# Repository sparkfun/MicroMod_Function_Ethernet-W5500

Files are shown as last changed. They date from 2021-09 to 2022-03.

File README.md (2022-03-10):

SparkFun MicroMod Ethernet Function Board - W5500
========================================

SparkFun MicroMod Ethernet Function Board - W5500 (https://www.sparkfun.com/products/18708)

[*SparkFun MicroMod Ethernet Function Board - W5500 (COM-18708)*](https://www.sparkfun.com/products/18708)

The SparkFun MicroMod Ethernet Function Board - W5500 provides Ethernet network connection as well as Power-over-Ethernet capabilities to a MicroMod project.

The W5500 Ethernet Controller from WIZnet is a TCP/IP embedded Ethernet controller that uses SPI communication protocol to allow up to eight independent sockets operate simultaneously. The W5500 SPI interface operates at up to 80MHz and supports fast SPI for high speed Ethernet communication. The chip also includes a Wake on Lan (WOL) operation and power down mode to help conserve power.

The board uses a Ag9900m Power-over-Ethernet (PoE) DC/DC converter module to power MicroMod assemblies from a PoE source such as a router or network switch. The DC/DC converter supplies 9 Watts @5V to connected devices. This Function Board configures the PoE supply voltage to the IEEE802.3af Alternate B power scheme. This power scheme uses the spare pairs in the Ethernet cable (4,5 and 7,8) for positive and negative DC voltage, isolating power delivery from the data lines.

Repository Contents
-------------------

* **/Documents** - Datasheet, Appnotes.
* **/Firmware** - HTTP Test.
* **/Hardware** - Eagle design files (.brd, .sch)

Documentation
-------------

* **[Hookup Guide](https://learn.sparkfun.com/tutorials/micromod-ethernet-function-board---w5500-hookup-guide)** - A basic Hookup Guide to get started with the MicroMod Ethernet Function Board - W5500.

Product Versions
----------------
* [COM-18708](https://www.sparkfun.com/products/18708) - Initial release

Version History
---------------
* v1.0 - Initial Release 

License Information
-------------------

This product is _**open source**_! 

Please review the LICENSE.md file for license information. 

If you have any questions or concerns on licensing, please contact technical support on our [SparkFun forums](https://forum.sparkfun.com/viewforum.php?f=152).

Distributed as-is; no warranty is given.

- Your friends at SparkFun.

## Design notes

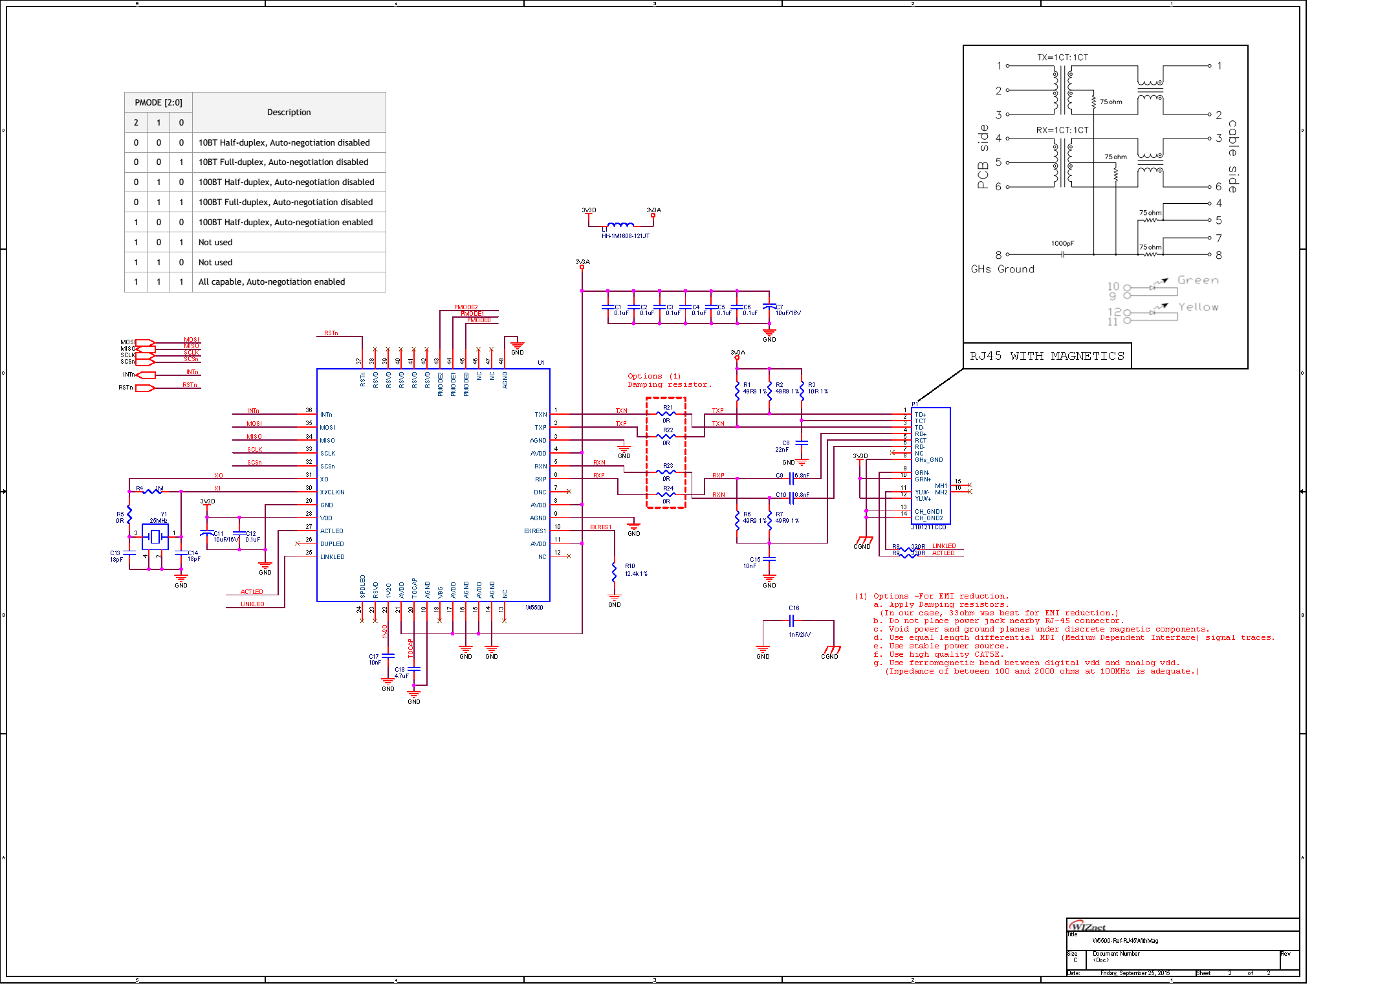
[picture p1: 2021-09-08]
Documents/w5500_sch.png

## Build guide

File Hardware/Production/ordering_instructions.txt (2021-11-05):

panel size, 129x137mm
PCB thickness, 0.8mm
number of layers, 2
bevel, Gold Fingers + 45° Finger Chamfered
soldermask color, Red
silkscreen color, White
oz copper, 1oz
finish, ENIG
stencils, none
pcs per panel, 6
min trace width, 0.1778mm / 0.0070in
min drill size, 0.3048mm / 0.0120in

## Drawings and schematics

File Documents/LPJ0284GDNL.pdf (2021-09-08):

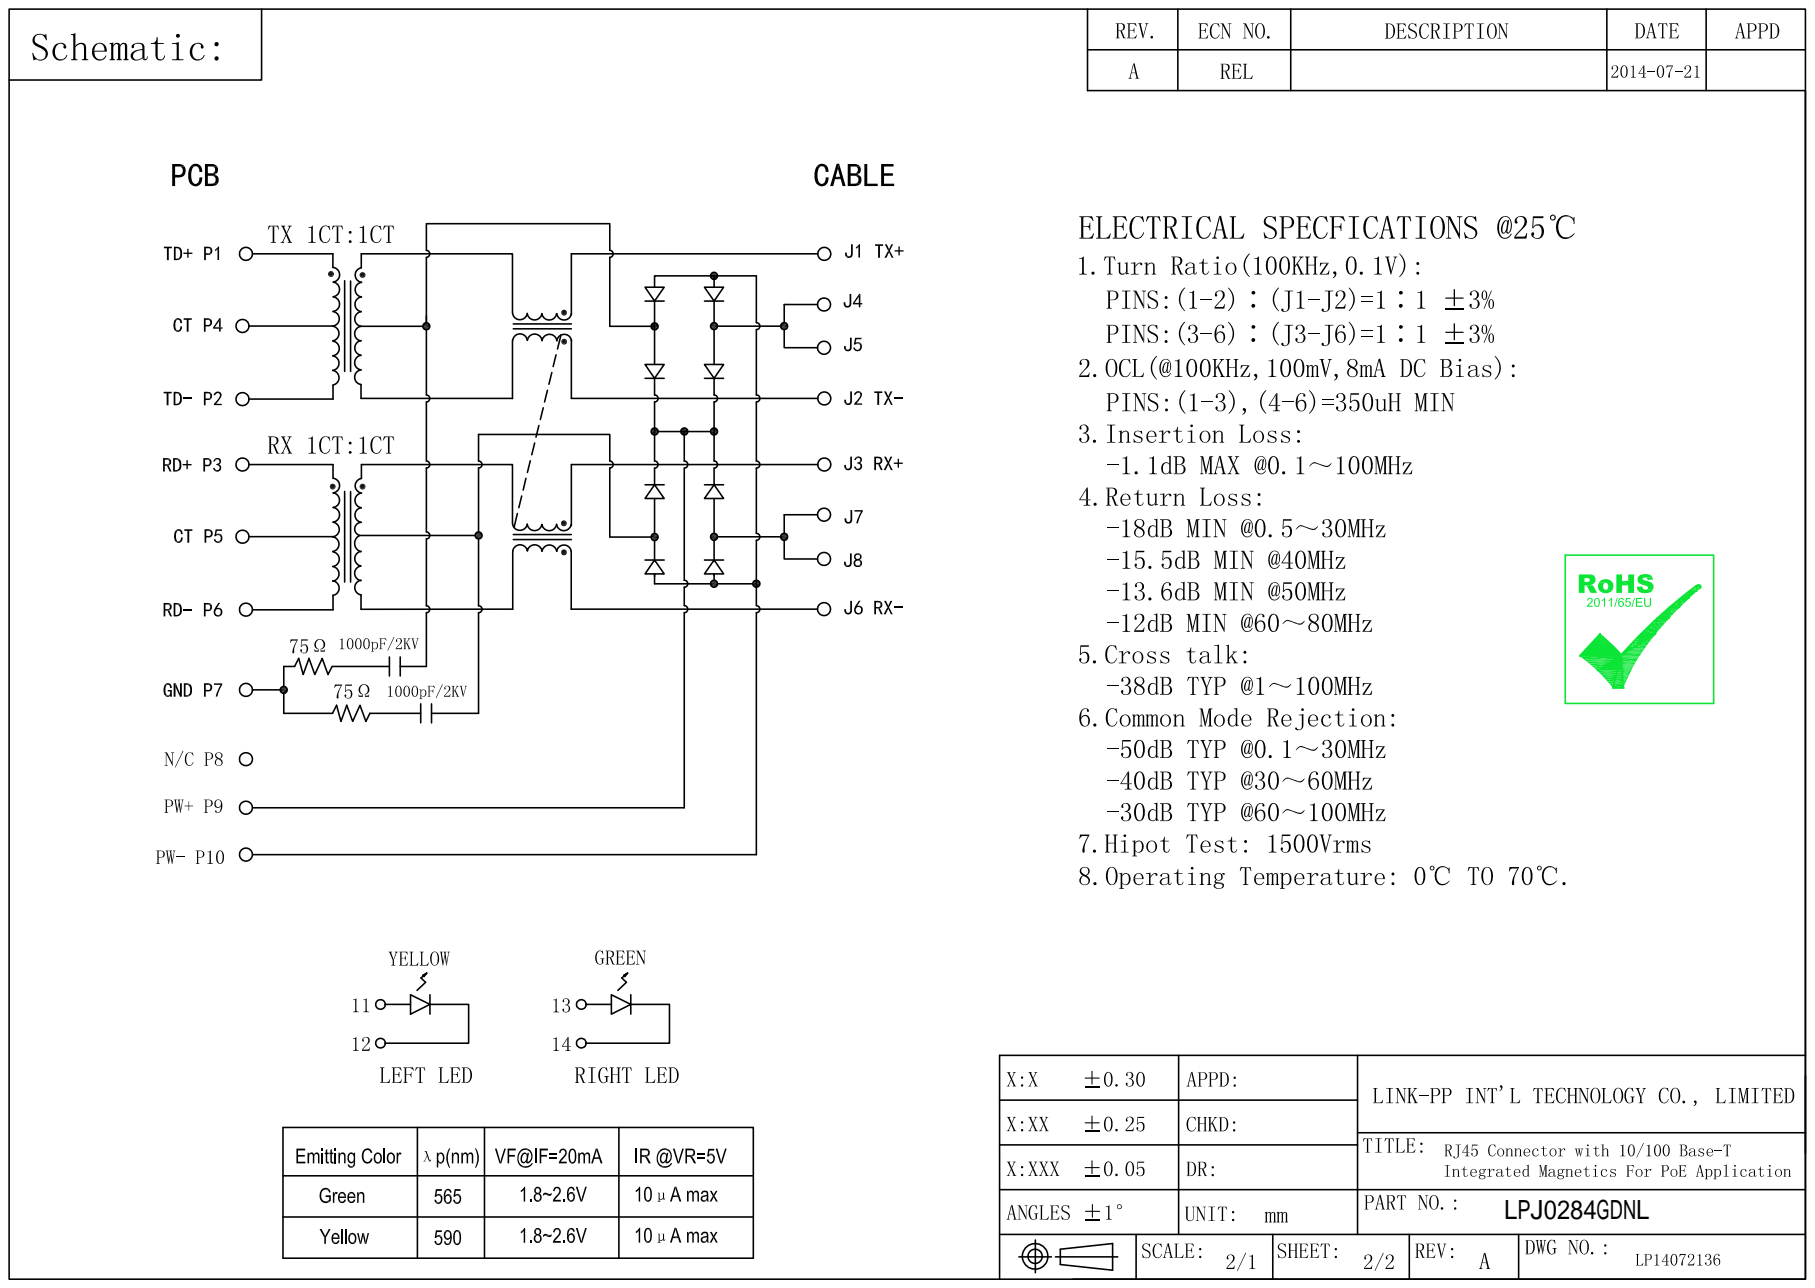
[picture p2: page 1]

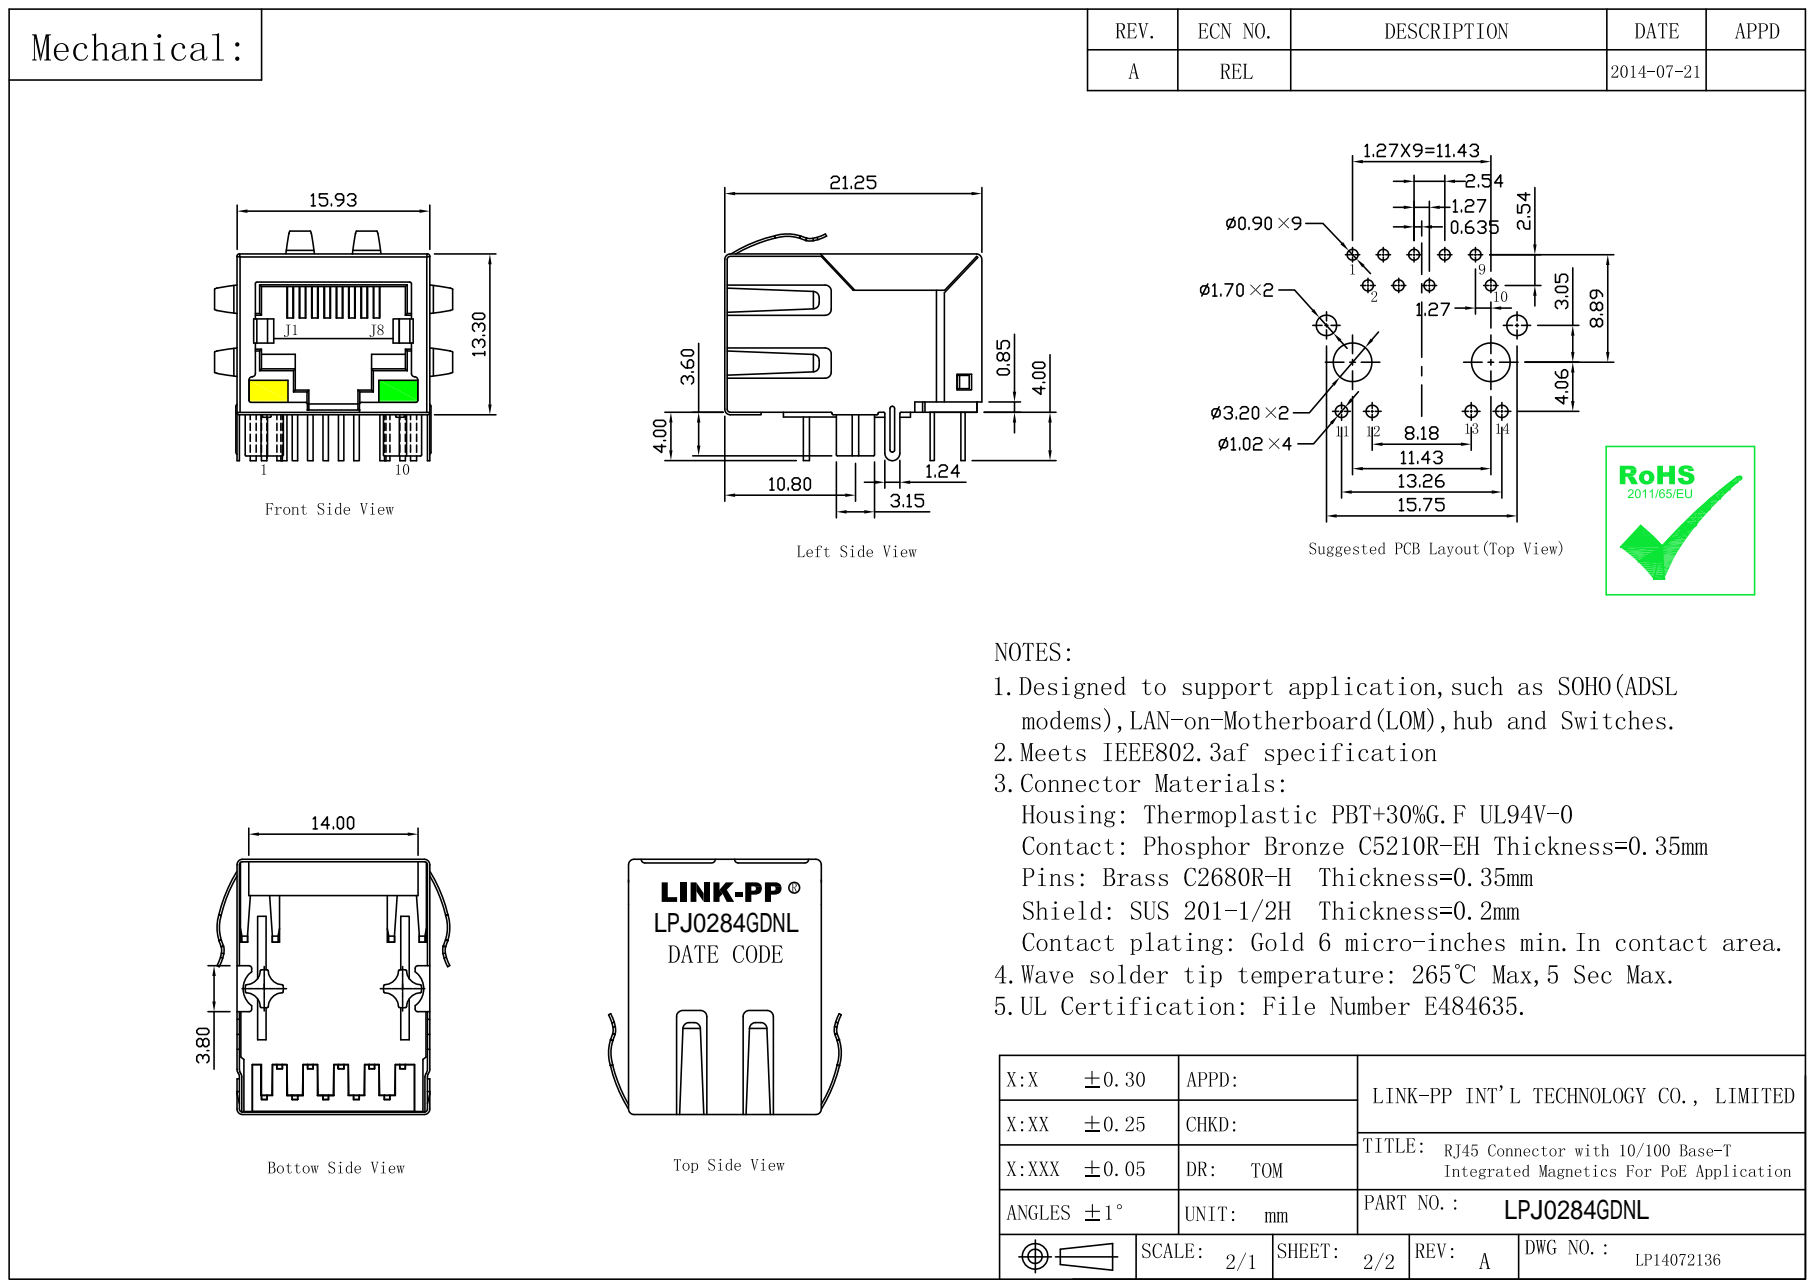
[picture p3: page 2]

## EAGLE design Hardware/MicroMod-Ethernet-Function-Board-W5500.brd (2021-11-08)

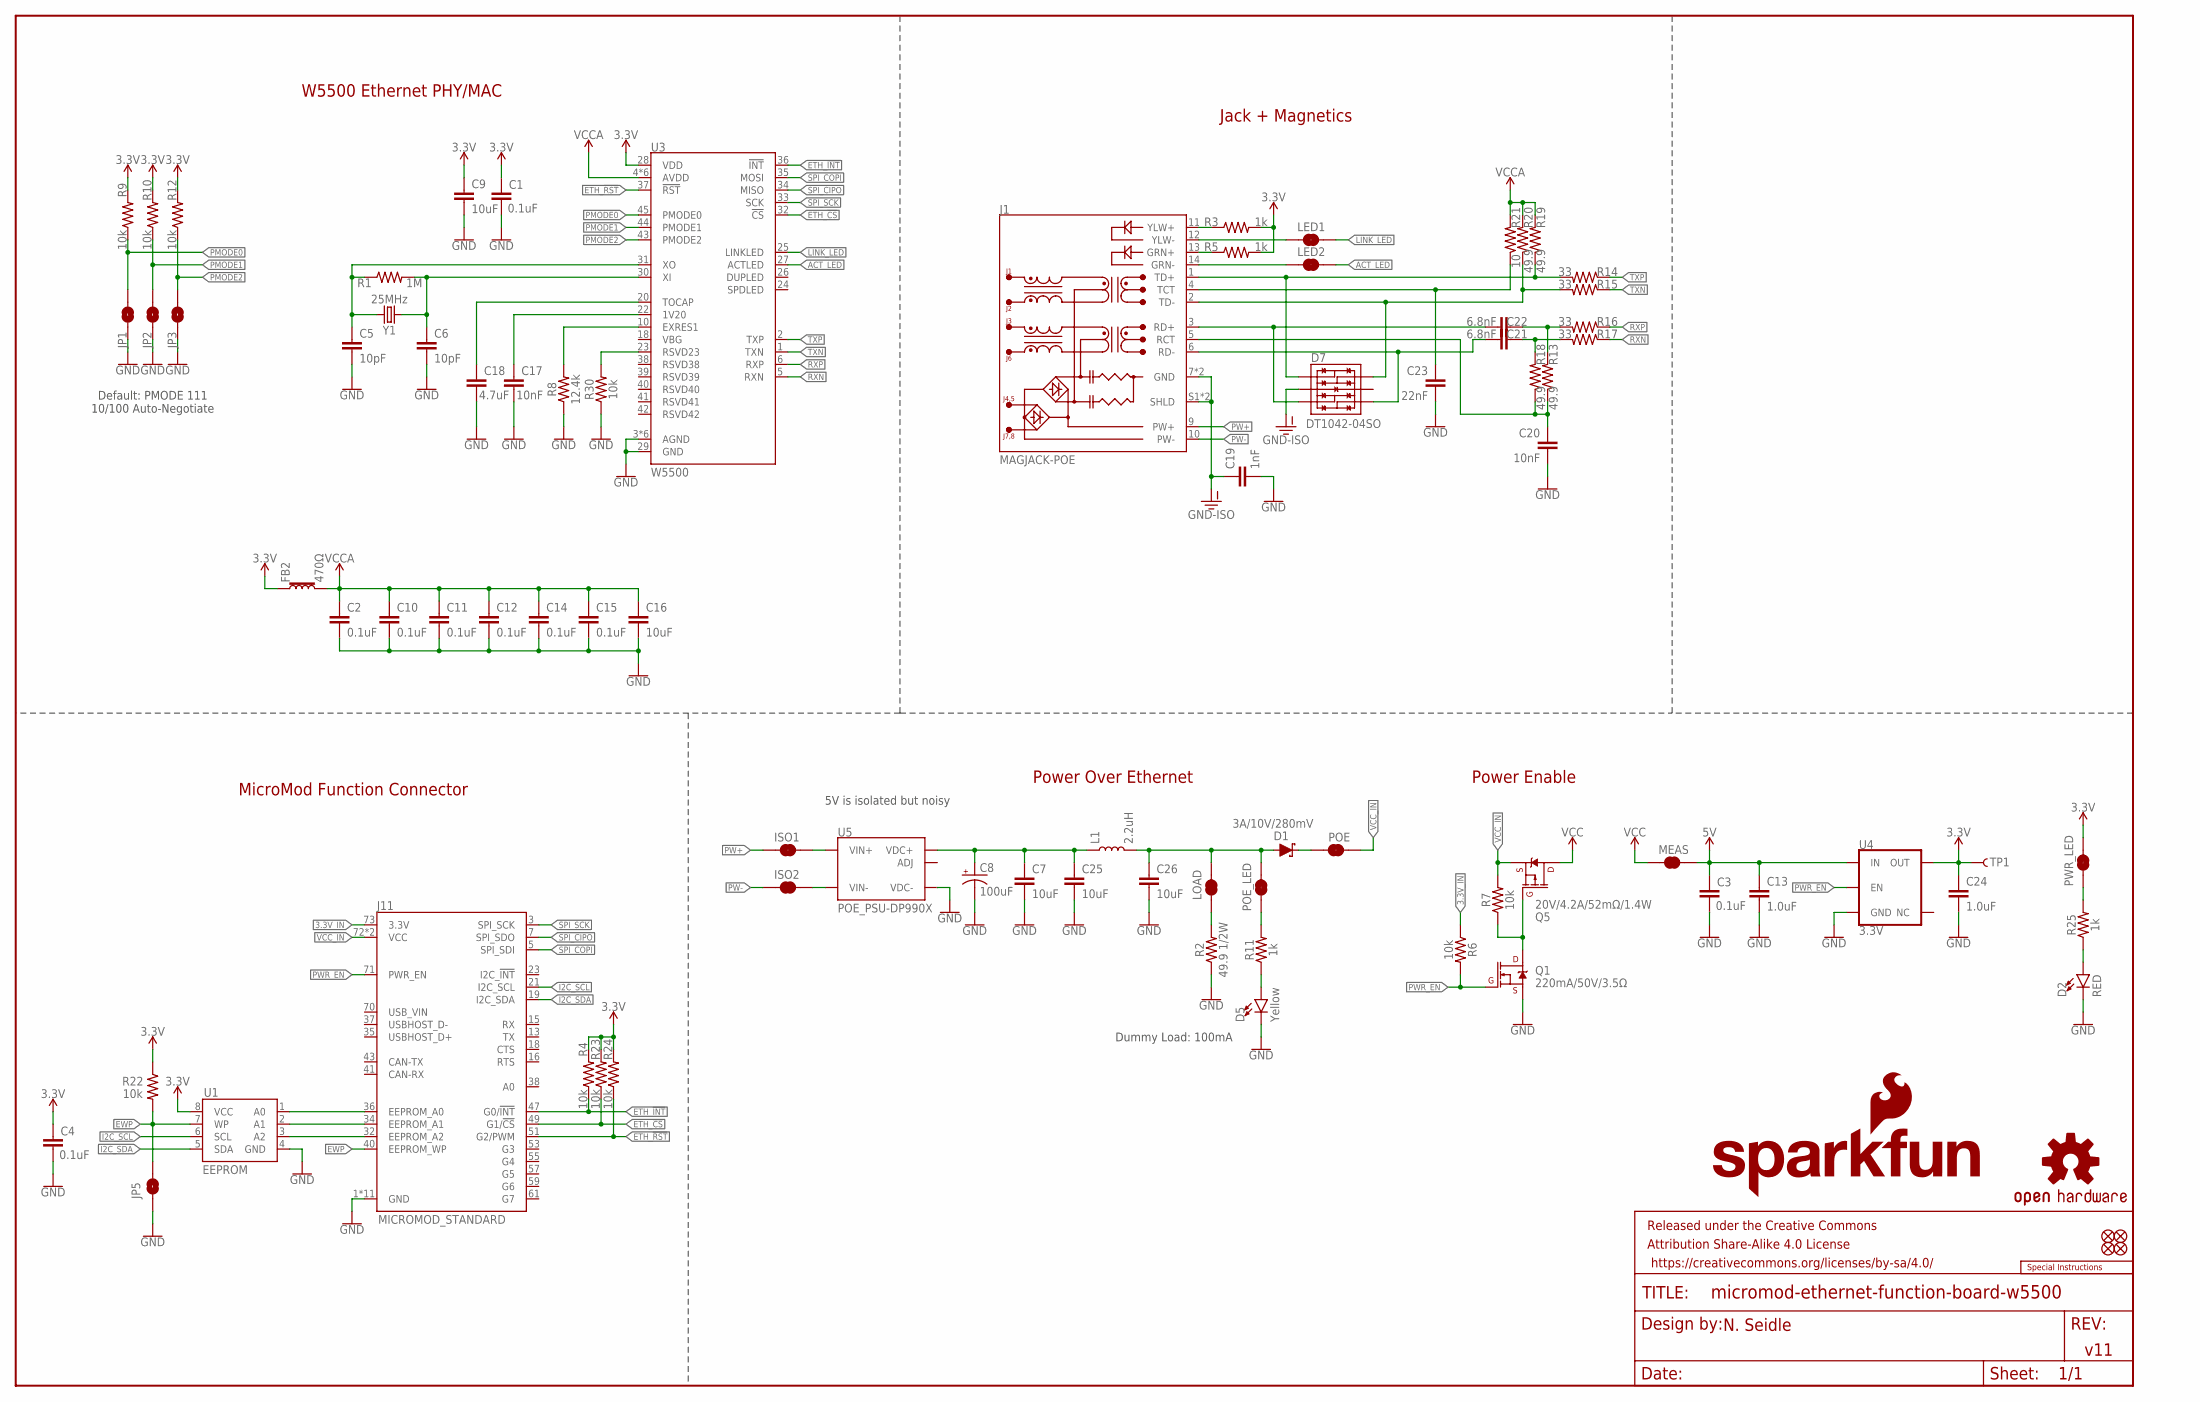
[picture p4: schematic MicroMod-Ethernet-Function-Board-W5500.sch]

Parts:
C1, C2, C3, C4, C10, C11, C12, C14, C15: 0.1uF; 0603
C5, C6: 10pF; 0603
C7, C25, C26: 10uF; 0805
C8: 100uF; PANASONIC_D
C9, C16: 10uF; 0603
C13, C24: 1.0uF; 0603
C17, C20: 10nF; 0603
C18: 4.7uF; 0603
C19: 1nF; 1206
C21, C22: 6.8nF; 0603
C23: 22nF; 0603
D1: 3A/10V/280mV; SOD-323
D2: RED; LED-0603
D5: Yellow; LED-0603
D7: DT1042-04SO; SOT-23-6
FB2: 470Ω; 0603
FD1, FD2, FD3, FD4: FIDUCIALUFIDUCIAL; FIDUCIAL-MICRO
FRAME1: FRAME-LEDGER; CREATIVE_COMMONS
ISO1, ISO2: JUMPER-COMBO_2_NC_TRACE; COMBO-JUMPER_2_NC_TRACE
J1: MAGJACK-POE; MAGJACK-SYM_LED
J11: MICROMOD_STANDARD; M.2-CARD-E-22_FUNCTION_STANDARD
JP1, JP2, JP3, JP5: JUMPER-SMT_2_NO_SILK; SMT-JUMPER_2_NO_SILK
L1: 2.2uH; 0805-WIDE
LED1, LED2: JUMPER-SMT_2_NC_TRACE_SILK; SMT-JUMPER_2_NC_TRACE_SILK
LOAD: JUMPER-SMT_2_NC_TRACE_SILK; SMT-JUMPER_2_NC_TRACE_SILK
LOGO1: SFE_LOGO_NAME_FLAME.1_INCH; SFE_LOGO_NAME_FLAME_.1
LOGO2: SPECIAL_INSTRUCTIONS-ORDERING; ORDERING_INSTRUCTIONS
LOGO3: OSHW-LOGOMINI; OSHW-LOGO-MINI
MEAS: JUMPER-COMBO_2_NC_TRACE; COMBO-JUMPER_2_NC_TRACE
POE: JUMPER-SMT_2_NC_TRACE_SILK; SMT-JUMPER_2_NC_TRACE_SILK
POE_LED: JUMPER-SMT_2_NC_TRACE_SILK; SMT-JUMPER_2_NC_TRACE_SILK
PWR_LED: JUMPER-SMT_2_NC_TRACE_SILK; SMT-JUMPER_2_NC_TRACE_SILK
Q1: 220mA/50V/3.5Ω; SOT23-3
Q5: 20V/4.2A/52mΩ/1.4W; SOT23-3
R1: 1M; 0603
R2: 49.9 1/2W; 1206
R3, R5, R11, R25: 1k; 0603
R4, R6, R7, R9, R10, R12, R22, R23, R24, R30: 10k; 0603
R8: 12.4k; 0603
R13, R18, R19, R20: 49.9; 0603
R14, R15, R16, R17: 33; 0603
R21: 10; 0603
TP1: TEST-POINT3X4; PAD.03X.04
U1: EEPROM; SO08
U3: W5500; LQFP-48
U4: 3.3V; SOT23-5
U5: POE_PSU-DP990X; DP990X
Y1: 25MHz; CRYSTAL-SMD-2.0X1.6MM

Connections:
3.3V: C1.1, C4.1, C9.1, C24.1, FB2.1, PWR_LED.2, R3.2, R4.2, R5.2, R9.2, R10.2, R12.2, R22.1, R23.2, R24.2, TP1.1, U1.8 (VCC), U3.28 (VDD), U4.5 (OUT)
3.3V_IN: J11.73 (3.3V), R6.1
5V: C3.1, C13.1, MEAS.2, MEAS.4 (2), U4.1 (IN)
5V_FILTER: C26.1, D1.A, L1.2, LOAD.2, POE_LED.2
5V_RAW: C7.1, C8.+, C25.1, L1.1, U5.1 (VDC+), U5.2 (VDC+)
A0: J11.36 (EEPROM_A0), U1.1 (A0)
A1: J11.34 (EEPROM_A1), U1.2 (A1)
A2: J11.32 (EEPROM_A2), U1.3 (A2)
ACT_LED: LED2.2, U3.27 (ACTLED)
ETH_!CS!: J11.49 (G1/!CS!), R23.1, U3.32 (!CS!)
ETH_!INT!: J11.47 (G0/!INT!), R4.1, U3.36 (!INT!)
ETH_!RST!: J11.51 (G2/PWM), R24.1, U3.37 (!RST!)
EWP: J11.40 (EEPROM_WP), JP5.2, R22.2, U1.7 (WP)
GND: C1.2, C2.2, C3.2, C4.2, C5.2, C6.2, C7.2, C8.-, C9.2, C10.2, C11.2, C12.2, C13.2, C14.2, C15.2, C16.2, C17.2, C18.2, C19.2, C20.2, C23.2, C24.2, C25.2, C26.2, D2.C, D5.C, J11.1 (GND), J11.33 (GND), J11.39 (GND), J11.45 (GND), J11.75 (GND), J11.GND1 (GND), J11.GND2 (GND), J11.GND3 (GND), J11.GND4 (GND), J11.GND5 (GND), J11.GND6 (GND), JP1.1, JP2.1, JP3.1, JP5.1, Q1.2 (S), R2.1, R8.1, R30.1, U1.4 (GND), U3.3 (AGND), U3.9 (AGND), U3.14 (AGND), U3.16 (AGND), U3.19 (AGND), U3.29 (GND), U3.48 (AGND), U4.2 (GND), U5.3 (VDC-)
GND-ISO: C19.1, D7.2 (VSS), J1.7 (GND), J1.8 (GND), J1.S1 (SHLD), J1.S2 (SHLD)
I2C_SCL: J11.21 (I2C_SCL), U1.6 (SCL)
I2C_SDA: J11.19 (I2C_SDA), U1.5 (SDA)
LINK_LED: LED1.2, U3.25 (LINKLED)
unnamed: C5.1, R1.1, U3.31 (XO), Y1.1
unnamed: C6.1, R1.2, U3.30 (XI), Y1.3 (2)
unnamed: J1.14 (GRN-), LED2.1
unnamed: J1.12 (YLW-), LED1.1
unnamed: D5.A, R11.1
unnamed: POE_LED.1, R11.2
unnamed: D1.C, POE.1
unnamed: J1.13 (GRN+), R5.1
unnamed: LOAD.1, R2.2
unnamed: J1.11 (YLW+), R3.1
unnamed: Q1.3 (D), Q5.1 (G), R7.1
unnamed: R8.2, U3.10 (EXRES1)
unnamed: C17.1, U3.22 (1V20)
unnamed: C18.1, U3.20 (TOCAP)
unnamed: R30.2, U3.23 (RSVD23)
unnamed: PWR_LED.1, R25.2
unnamed: D2.A, R25.1
PMODE0: JP1.2, R9.1, U3.45 (PMODE0)
PMODE1: JP2.2, R10.1, U3.44 (PMODE1)
PMODE2: JP3.2, R12.1, U3.43 (PMODE2)
PW1+: ISO1.2, ISO1.4 (2), U5.5 (VIN+), U5.6 (VIN+)
PW1-: ISO2.2, ISO2.4 (2), U5.7 (VIN-), U5.8 (VIN-)
PW+: ISO1.1, ISO1.3 (1), J1.9 (PW+)
PW-: ISO2.1, ISO2.3 (1), J1.10 (PW-)
PWR_EN: J11.71 (PWR_EN), Q1.1 (G), R6.2, U4.3 (EN)
RCT: C20.1, J1.5 (RCT), R13.1, R18.1
RD+: C22.2, D7.3 (IO2), J1.3 (RD+)
RD-: C21.2, D7.4 (IO3), J1.6 (RD-)
RXN: R17.1, U3.5 (RXN)
RXN1: C21.1, R17.2, R18.2
RXP: R16.1, U3.6 (RXP)
RXP1: C22.1, R13.2, R16.2
SPI_CIPO: J11.7 (SPI_SDO), U3.34 (MISO)
SPI_COPI: J11.5 (SPI_SDI), U3.35 (MOSI)
SPI_SCK: J11.3 (SPI_SCK), U3.33 (SCK)
TCT: C23.1, J1.4 (TCT), R21.1
TD+: D7.1 (IO1), J1.1 (TD+), R14.2, R19.1
TD-: D7.6 (IO4), J1.2 (TD-), R15.2, R20.1
TXN: R15.1, U3.1 (TXN)
TXP: R14.1, U3.2 (TXP)
VCC: MEAS.1, MEAS.3 (1), Q5.3 (D)
VCCA: C2.1, C10.1, C11.1, C12.1, C14.1, C15.1, C16.1, FB2.2, R19.2, R20.2, R21.2, U3.4 (AVDD), U3.8 (AVDD), U3.11 (AVDD), U3.15 (AVDD), U3.17 (AVDD), U3.21 (AVDD)
VCC_IN: J11.72 (VCC), J11.74 (VCC), POE.2, Q5.2 (S), R7.2

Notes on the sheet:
Power Over Ethernet
MicroMod Function Connector
5V is isolated but noisy
N. Seidle
v11
W5500 Ethernet PHY/MAC
Power Enable
Default: PMODE 111 10/100 Auto-Negotiate
Jack + Magnetics
Dummy Load: 100mA

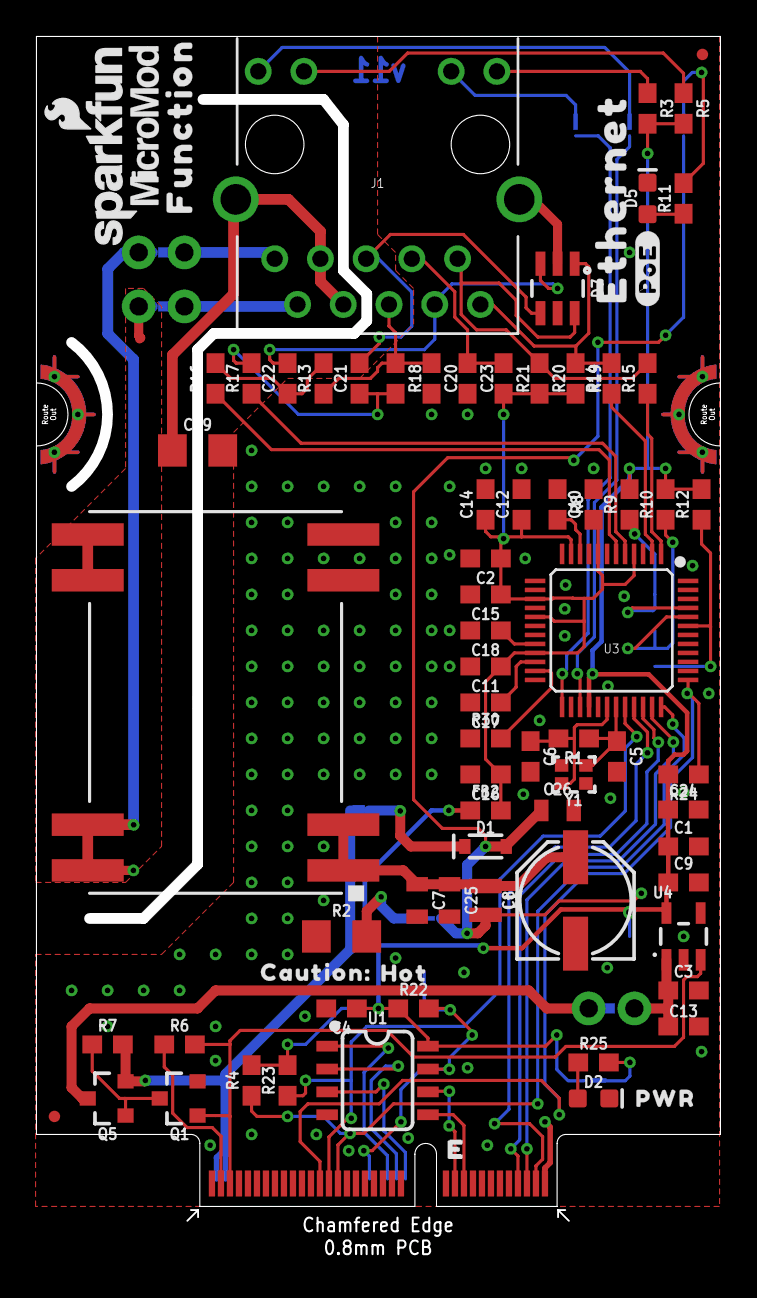
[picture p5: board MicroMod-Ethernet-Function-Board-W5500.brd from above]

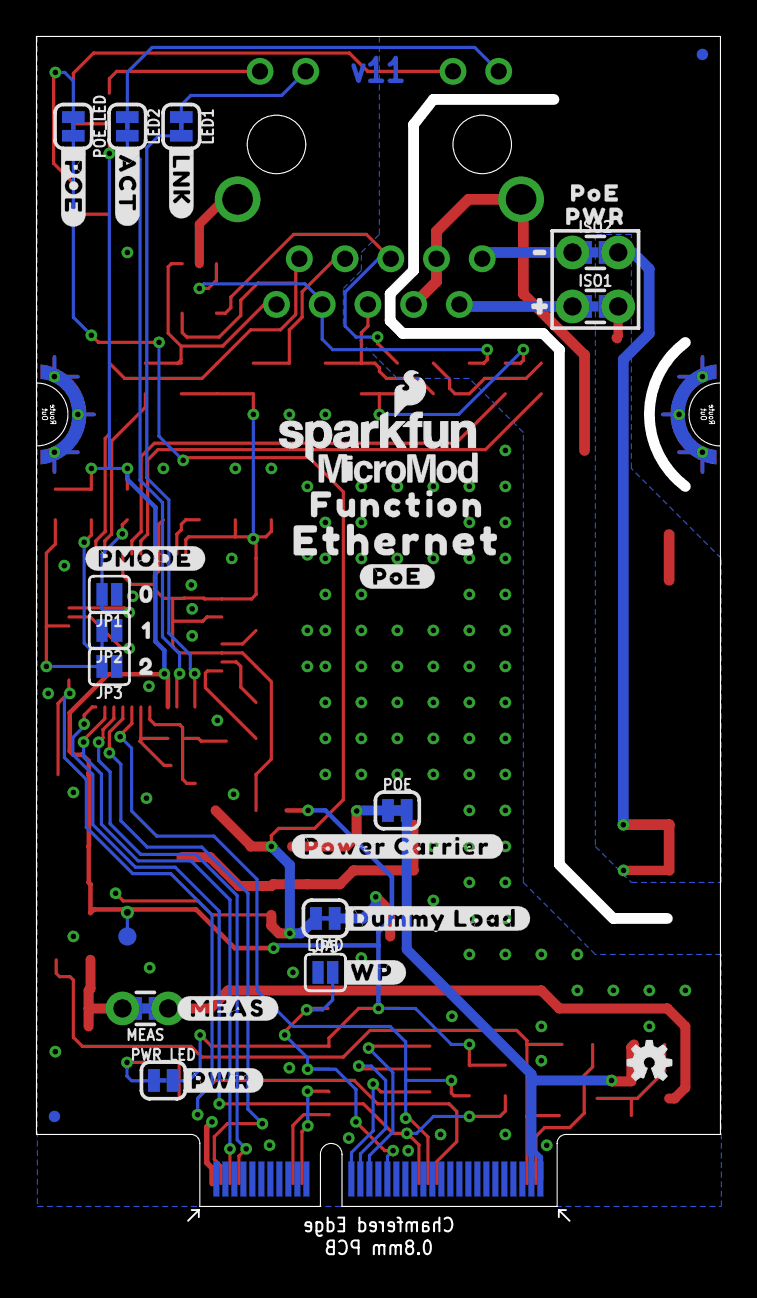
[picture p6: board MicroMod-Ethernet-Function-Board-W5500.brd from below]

Board: 2 copper layers, 38.0 x 65.8 mm, 117 parts (38 on the bottom side), 61 nets.

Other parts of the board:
LOGO4: SFE_LOGO_NAME_FLAME.1_INCH; SFE_LOGO_NAME_FLAME_.1
U$1, U$17: ETHERNET0
U$2, U$18: #POE#0
U$3: #POWER_CARRIER#0
U$5: #DUMMY_LOAD#0
U$6: #WP#0
U$7: PWR0
U$8: #ACT#0
U$9: POE0
U$12: #LNK#1
U$13: #PMODE#0
U$14: 01
U$15: 12
U$16: 23
U$19: #0
U$20: CAUTION#0
U$21: HOT#1
U$22: #PWR#0
U$23: #_POE#0
U$24: PWR1
U$25: #1
U$26, U$27: FUNCTION0
U$28: #MEAS#3
U$37, U$63: MICROMOD_LOGO_.35

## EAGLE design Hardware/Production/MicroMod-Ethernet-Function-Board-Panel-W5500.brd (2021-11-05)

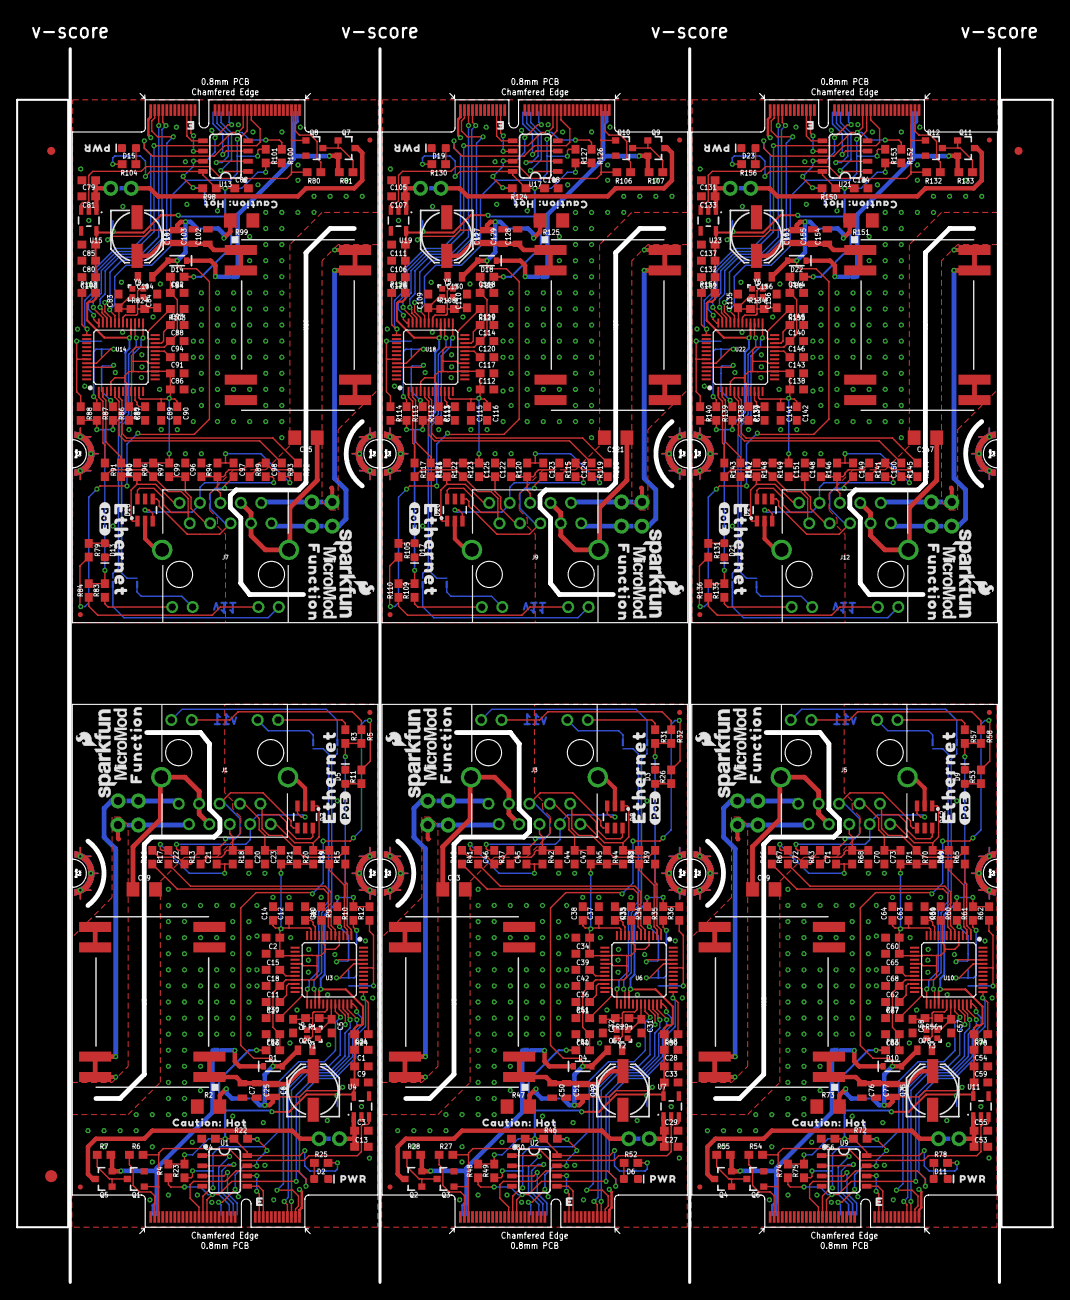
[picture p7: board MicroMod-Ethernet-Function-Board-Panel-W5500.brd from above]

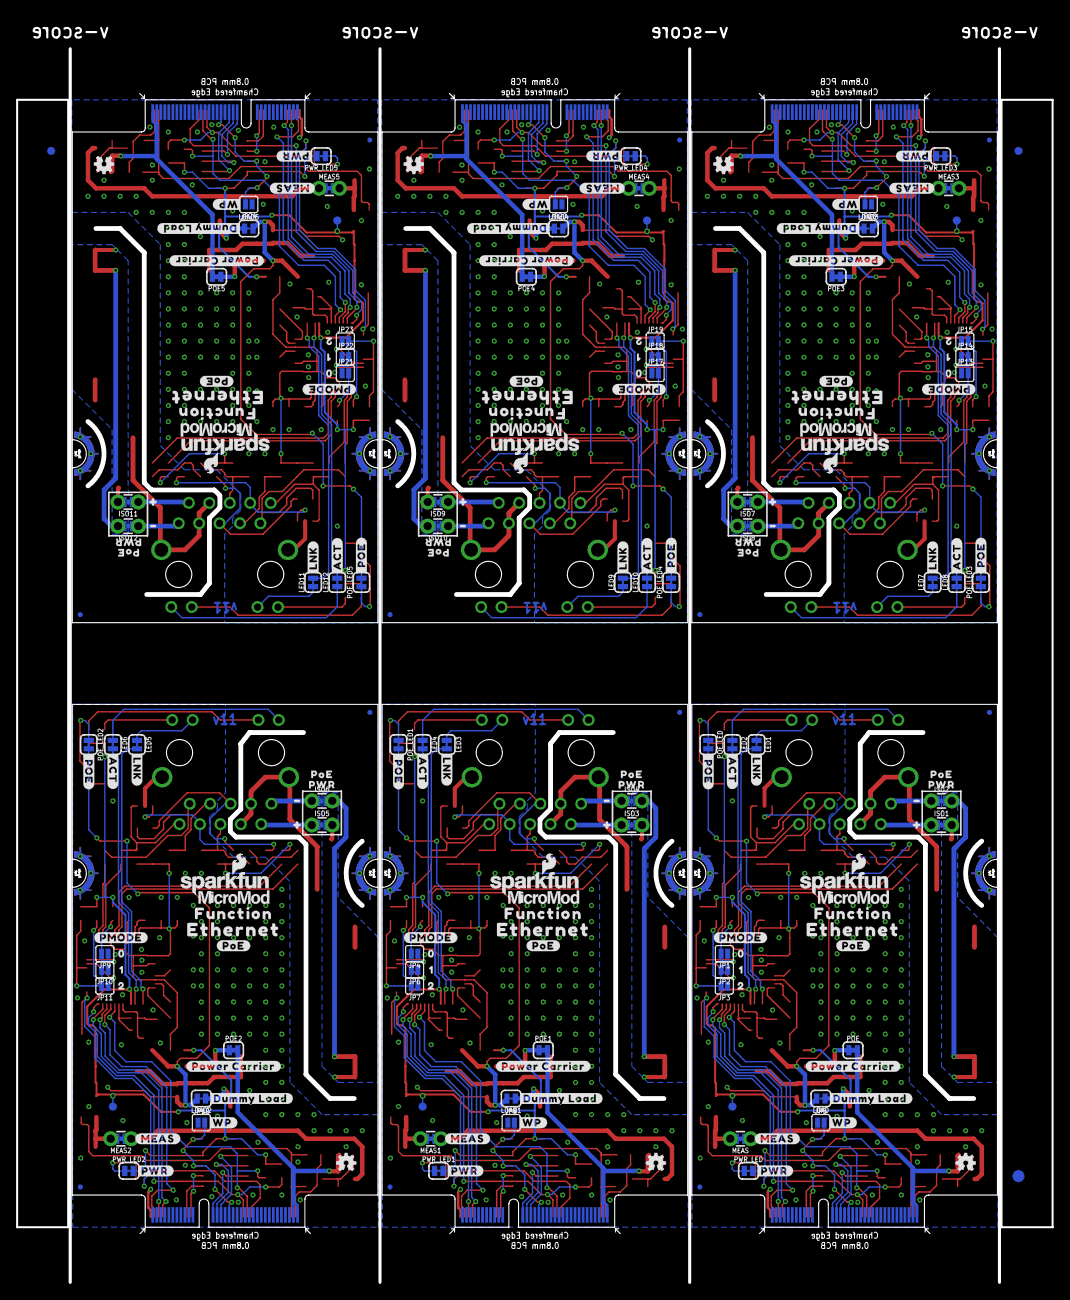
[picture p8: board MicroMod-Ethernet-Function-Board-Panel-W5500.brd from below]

Board: 2 copper layers, 128.7 x 153.4 mm, 696 parts (231 on the bottom side), 366 nets.

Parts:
C1, C2, C3, C4, C10, C11, C12, C14, C15, C28, C29, C30, C34, C35, C36, C37, C38, C39, C54, C55, C56, C60, C61, C62, C63, C64, C65, C80, C81, C82, C86, C87, C88, C89, C90, C91, C106, C107, C108, C112, C113, C114, C115, C116, C117, C132, C133, C134, C138, C139, C140, C141, C142, C143: 0.1uF; 0603
C5, C6, C31, C32, C57, C58, C83, C84, C109, C110, C135, C136: 10pF; 0603
C7, C25, C26, C50, C51, C52, C76, C77, C78, C102, C103, C104, C128, C129, C130, C154, C155, C156: 10uF; 0805
C8, C49, C75, C101, C127, C153: 100uF; PANASONIC_D
C9, C16, C33, C40, C59, C66, C85, C92, C111, C118, C137, C144: 10uF; 0603
C13, C24, C27, C48, C53, C74, C79, C100, C105, C126, C131, C152: 1.0uF; 0603
C17, C20, C41, C44, C67, C70, C93, C96, C119, C122, C145, C148: 10nF; 0603
C18, C42, C68, C94, C120, C146: 4.7uF; 0603
C19, C43, C69, C95, C121, C147: 1nF; 1206
C21, C22, C45, C46, C71, C72, C97, C98, C123, C124, C149, C150: 6.8nF; 0603
C23, C47, C73, C99, C125, C151: 22nF; 0603
D1, D4, D10, D14, D18, D22: 3A/10V/280mV; SOD-323
D2, D6, D11, D15, D19, D23: RED; LED-0603
D3, D5, D9, D13, D17, D21: Yellow; LED-0603
D7, D8, D12, D16, D20, D24: DT1042-04SO; SOT-23-6
E$1, E$2, E$3, E$4: FIDUCIAL-1X2
E$5, E$6: FIDUCIAL-1.5X3
FB1, FB2, FB3, FB4, FB5, FB6: 470Ω; 0603
FD1, FD2, FD3, FD4, FD5, FD6, FD7, FD8, FD9, FD10, FD11, FD12, FD13, FD14, FD15, FD16, FD17, FD18, FD19, FD20, FD21, FD22, FD23, FD24: FIDUCIALUFIDUCIAL; FIDUCIAL-MICRO
ISO1, ISO2, ISO3, ISO4, ISO5, ISO6, ISO7, ISO8, ISO9, ISO10, ISO11, ISO12: JUMPER-COMBO_2_NC_TRACE; COMBO-JUMPER_2_NC_TRACE
J1, J3, J5, J7, J9, J12: MAGJACK-POE; MAGJACK-SYM_LED
J2, J4, J6, J8, J10, J11: MICROMOD_STANDARD; M.2-CARD-E-22_FUNCTION_STANDARD
JP1, JP2, JP3, JP4, JP5, JP6, JP7, JP8, JP9, JP10, JP11, JP12, JP13, JP14, JP15, JP16, JP17, JP18, JP19, JP20, JP21, JP22, JP23, JP24: JUMPER-SMT_2_NO_SILK; SMT-JUMPER_2_NO_SILK
L1, L2, L3, L4, L5, L6: 2.2uH; 0805-WIDE
LED1, LED2, LED3, LED4, LED5, LED6, LED7, LED8, LED9, LED10, LED11, LED12: JUMPER-SMT_2_NC_TRACE_SILK; SMT-JUMPER_2_NC_TRACE_SILK
LOAD, LOAD1, LOAD2, LOAD3, LOAD4, LOAD5: JUMPER-SMT_2_NC_TRACE_SILK; SMT-JUMPER_2_NC_TRACE_SILK
LOGO1, LOGO2, LOGO4, LOGO6, LOGO7, LOGO9, LOGO10, LOGO12, LOGO13, LOGO15, LOGO16, LOGO18: SFE_LOGO_NAME_FLAME.1_INCH; SFE_LOGO_NAME_FLAME_.1
LOGO3, LOGO5, LOGO8, LOGO11, LOGO14, LOGO17: OSHW-LOGOMINI; OSHW-LOGO-MINI
MEAS, MEAS1, MEAS2, MEAS3, MEAS4, MEAS5: JUMPER-COMBO_2_NC_TRACE; COMBO-JUMPER_2_NC_TRACE
POE, POE1, POE2, POE3, POE4, POE5: SMT-JUMPER_2_NC_TRACE_SILK
POE_LED, POE_LED1, POE_LED2, POE_LED3, POE_LED4, POE_LED5: JUMPER-SMT_2_NC_TRACE_SILK; SMT-JUMPER_2_NC_TRACE_SILK
PWR_LED, PWR_LED1, PWR_LED2, PWR_LED3, PWR_LED4, PWR_LED5: JUMPER-SMT_2_NC_TRACE_SILK; SMT-JUMPER_2_NC_TRACE_SILK
Q1, Q3, Q6, Q8, Q10, Q12: 220mA/50V/3.5Ω; SOT23-3
Q2, Q4, Q5, Q7, Q9, Q11: 20V/4.2A/52mΩ/1.4W; SOT23-3
R1, R29, R56, R82, R108, R134: 1M; 0603
R2, R47, R73, R99, R125, R151: 49.9 1/2W; 1206
R3, R5, R11, R25, R26, R31, R32, R52, R53, R57, R58, R78, R79, R83, R84, R104, R105, R109, R110, R130, R131, R135, R136, R156: 1k; 0603
R4, R6, R7, R9, R10, R12, R22, R23, R24, R27, R28, R30, R34, R35, R36, R46, R48, R49, R50, R51, R54, R55, R60, R61, R62, R72, R74, R75, R76, R77, R80, R81, R86, R87, R88, R98, R100, R101, R102, R103, R106, R107, R112, R113, R114, R124, R126, R127, R128, R129, R132, R133, R138, R139, R140, R150, R152, R153, R154, R155: 10k; 0603
R8, R33, R59, R85, R111, R137: 12.4k; 0603
R13, R18, R19, R20, R37, R42, R43, R44, R63, R68, R69, R70, R89, R94, R95, R96, R115, R120, R121, R122, R141, R146, R147, R148: 49.9; 0603
R14, R15, R16, R17, R38, R39, R40, R41, R64, R65, R66, R67, R90, R91, R92, R93, R116, R117, R118, R119, R142, R143, R144, R145: 33; 0603
R21, R45, R71, R97, R123, R149: 10; 0603
TP1, TP2, TP3, TP4, TP5, TP6: TEST-POINT3X4; PAD.03X.04
U1, U2, U9, U13, U17, U21: EEPROM; SO08
U3, U6, U10, U14, U18, U22: W5500; LQFP-48
U4, U7, U11, U15, U19, U23: 3.3V; SOT23-5
U5, U8, U12, U16, U20, U24: POE_PSU-DP990X; DP990X
U$1, U$17, U$34, U$36, U$62, U$65, U$90, U$92, U$117, U$119, U$144, U$146: ETHERNET0
U$2, U$18, U$35, U$38, U$64, U$66, U$91, U$93, U$118, U$120, U$145, U$147: #POE#0
U$3, U$39, U$67, U$94, U$121, U$148: #POWER_CARRIER#0
U$4, U$10, U$37, U$54, U$55, U$63, U$82, U$83, U$109, U$110, U$136, U$137: MICROMOD_LOGO_.35
U$5, U$40, U$68, U$95, U$122, U$149: #DUMMY_LOAD#0
U$6, U$41, U$69, U$96, U$123, U$150: #WP#0
U$7, U$29, U$57, U$85, U$112, U$139: PWR0
U$8, U$42, U$70, U$97, U$124, U$151: #ACT#0
U$9, U$48, U$76, U$103, U$130, U$157: POE0
U$11, U$28, U$56, U$84, U$111, U$138: #MEAS#3
U$12, U$43, U$71, U$98, U$125, U$152: #LNK#1
U$13, U$30, U$58, U$86, U$113, U$140: #PMODE#0
U$14, U$31, U$59, U$87, U$114, U$141: 01
U$15, U$32, U$60, U$88, U$115, U$142: 12
U$16, U$33, U$61, U$89, U$116, U$143: 23
U$19, U$50, U$78, U$105, U$132, U$159: #0
U$20, U$44, U$72, U$99, U$126, U$153: CAUTION#0
U$21, U$45, U$73, U$100, U$127, U$154: HOT#1
U$22, U$46, U$74, U$101, U$128, U$155: #PWR#0
U$23, U$47, U$75, U$102, U$129, U$156: #_POE#0
U$24, U$49, U$77, U$104, U$131, U$158: PWR1
U$25, U$51, U$79, U$106, U$133, U$160: #1
U$26, U$27, U$52, U$53, U$80, U$81, U$107, U$108, U$134, U$135, U$161, U$162: FUNCTION0
Y1, Y2, Y3, Y4, Y5, Y6: 25MHz; CRYSTAL-SMD-2.0X1.6MM

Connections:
3.3V: C1.1, C4.1, C9.1, C24.1, FB2.1, PWR_LED.2, R3.2, R4.2, R5.2, R9.2, R10.2, R12.2, R22.1, R23.2, R24.2, TP1.1, U1.8, U3.28, U4.5
3.3V1: C28.1, C30.1, C33.1, C48.1, FB1.1, PWR_LED1.2, R31.2, R32.2, R34.2, R35.2, R36.2, R46.1, R48.2, R49.2, R50.2, TP2.1, U2.8, U6.28, U7.5
3.3V2: C54.1, C56.1, C59.1, C74.1, FB3.1, PWR_LED2.2, R57.2, R58.2, R60.2, R61.2, R62.2, R72.1, R74.2, R75.2, R76.2, TP3.1, U9.8, U10.28, U11.5
3.3V3: C80.1, C82.1, C85.1, C100.1, FB4.1, PWR_LED3.2, R83.2, R84.2, R86.2, R87.2, R88.2, R98.1, R100.2, R101.2, R102.2, TP4.1, U13.8, U14.28, U15.5
3.3V4: C106.1, C108.1, C111.1, C126.1, FB5.1, PWR_LED4.2, R109.2, R110.2, R112.2, R113.2, R114.2, R124.1, R126.2, R127.2, R128.2, TP5.1, U17.8, U18.28, U19.5
3.3V5: C132.1, C134.1, C137.1, C152.1, FB6.1, PWR_LED5.2, R135.2, R136.2, R138.2, R139.2, R140.2, R150.1, R152.2, R153.2, R154.2, TP6.1, U21.8, U22.28, U23.5
3.3V_IN: J11.73, R6.1
3.3V_IN1: J2.73, R27.1
3.3V_IN2: J4.73, R54.1
3.3V_IN3: J6.73, R80.1
3.3V_IN4: J8.73, R106.1
3.3V_IN5: J10.73, R132.1
5V: C3.1, C13.1, MEAS.2, MEAS.4, U4.1
5V1: C27.1, C29.1, MEAS1.2, MEAS1.4, U7.1
5V2: C53.1, C55.1, MEAS2.2, MEAS2.4, U11.1
5V3: C79.1, C81.1, MEAS3.2, MEAS3.4, U15.1
5V4: C105.1, C107.1, MEAS4.2, MEAS4.4, U19.1
5V5: C131.1, C133.1, MEAS5.2, MEAS5.4, U23.1
5V_FILTER: C26.1, D1.A, L1.2, LOAD.2, POE_LED.2
5V_FILTER1: C52.1, D4.A, L2.2, LOAD1.2, POE_LED1.2
5V_FILTER2: C78.1, D10.A, L3.2, LOAD2.2, POE_LED2.2
5V_FILTER3: C104.1, D14.A, L4.2, LOAD3.2, POE_LED3.2
5V_FILTER4: C130.1, D18.A, L5.2, LOAD4.2, POE_LED4.2
5V_FILTER5: C156.1, D22.A, L6.2, LOAD5.2, POE_LED5.2
5V_RAW: C7.1, C8.+, C25.1, L1.1, U5.1, U5.2
5V_RAW1: C49.+, C50.1, C51.1, L2.1, U8.1, U8.2
5V_RAW2: C75.+, C76.1, C77.1, L3.1, U12.1, U12.2
5V_RAW3: C101.+, C102.1, C103.1, L4.1, U16.1, U16.2
5V_RAW4: C127.+, C128.1, C129.1, L5.1, U20.1, U20.2
5V_RAW5: C153.+, C154.1, C155.1, L6.1, U24.1, U24.2
A0: J11.36, U1.1
A1: J11.34, U1.2
A2: J11.32, U1.3
A3: J2.36, U2.1
A4: J2.32, U2.3
A5: J2.34, U2.2
A6: J4.36, U9.1
A7: J4.32, U9.3
A8: J4.34, U9.2
A9: J6.36, U13.1
A10: J6.32, U13.3
A11: J6.34, U13.2
A12: J8.36, U17.1
A13: J8.32, U17.3
A14: J8.34, U17.2
A15: J10.36, U21.1
A16: J10.32, U21.3
A17: J10.34, U21.2
ACT_LED: LED2.2, U3.27
ACT_LED1: LED4.2, U6.27
ACT_LED2: LED6.2, U10.27
ACT_LED3: LED8.2, U14.27
ACT_LED4: LED10.2, U18.27
ACT_LED5: LED12.2, U22.27
ETH_!CS!: J11.49, R23.1, U3.32
ETH_!CS!1: J2.49, R49.1, U6.32
ETH_!CS!2: J4.49, R75.1, U10.32
ETH_!CS!3: J6.49, R101.1, U14.32
ETH_!CS!4: J8.49, R127.1, U18.32
ETH_!CS!5: J10.49, R153.1, U22.32
ETH_!INT!: J11.47, R4.1, U3.36
ETH_!INT!1: J2.47, R48.1, U6.36
ETH_!INT!2: J4.47, R74.1, U10.36
ETH_!INT!3: J6.47, R100.1, U14.36
ETH_!INT!4: J8.47, R126.1, U18.36
ETH_!INT!5: J10.47, R152.1, U22.36
ETH_!RST!: J11.51, R24.1, U3.37
ETH_!RST!1: J2.51, R50.1, U6.37
ETH_!RST!2: J4.51, R76.1, U10.37
ETH_!RST!3: J6.51, R102.1, U14.37
ETH_!RST!4: J8.51, R128.1, U18.37
ETH_!RST!5: J10.51, R154.1, U22.37
EWP: J11.40, JP5.2, R22.2, U1.7
EWP1: J2.40, JP8.2, R46.2, U2.7
EWP2: J4.40, JP12.2, R72.2, U9.7
EWP3: J6.40, JP16.2, R98.2, U13.7
EWP4: J8.40, JP20.2, R124.2, U17.7
EWP5: J10.40, JP24.2, R150.2, U21.7
GND: C1.2, C2.2, C3.2, C4.2, C5.2, C6.2, C7.2, C8.-, C9.2, C10.2, C11.2, C12.2, C13.2, C14.2, C15.2, C16.2, C17.2, C18.2, C19.2, C20.2, C23.2, C24.2, C25.2, C26.2, D2.C, D5.C, J11.1, J11.33, J11.39, J11.45, J11.75, J11.GND1, J11.GND2, J11.GND3, J11.GND4, J11.GND5, J11.GND6, JP1.1, JP2.1, JP3.1, JP5.1, Q1.2, R2.1, R8.1, R30.1, U1.4, U3.3, U3.9, U3.14, U3.16, U3.19, U3.29, U3.48, U4.2, U5.3
GND1: C27.2, C28.2, C29.2, C30.2, C31.2, C32.2, C33.2, C34.2, C35.2, C36.2, C37.2, C38.2, C39.2, C40.2, C41.2, C42.2, C43.2, C44.2, C47.2, C48.2, C49.-, C50.2, C51.2, C52.2, D3.C, D6.C, J2.1, J2.33, J2.39, J2.45, J2.75, J2.GND1, J2.GND2, J2.GND3, J2.GND4, J2.GND5, J2.GND6, JP4.1, JP6.1, JP7.1, JP8.1, Q3.2, R33.1, R47.1, R51.1, U2.4, U6.3, U6.9, U6.14, U6.16, U6.19, U6.29, U6.48, U7.2, U8.3
GND2: C53.2, C54.2, C55.2, C56.2, C57.2, C58.2, C59.2, C60.2, C61.2, C62.2, C63.2, C64.2, C65.2, C66.2, C67.2, C68.2, C69.2, C70.2, C73.2, C74.2, C75.-, C76.2, C77.2, C78.2, D9.C, D11.C, J4.1, J4.33, J4.39, J4.45, J4.75, J4.GND1, J4.GND2, J4.GND3, J4.GND4, J4.GND5, J4.GND6, JP9.1, JP10.1, JP11.1, JP12.1, Q6.2, R59.1, R73.1, R77.1, U9.4, U10.3, U10.9, U10.14, U10.16, U10.19, U10.29, U10.48, U11.2, U12.3
GND3: C79.2, C80.2, C81.2, C82.2, C83.2, C84.2, C85.2, C86.2, C87.2, C88.2, C89.2, C90.2, C91.2, C92.2, C93.2, C94.2, C95.2, C96.2, C99.2, C100.2, C101.-, C102.2, C103.2, C104.2, D13.C, D15.C, J6.1, J6.33, J6.39, J6.45, J6.75, J6.GND1, J6.GND2, J6.GND3, J6.GND4, J6.GND5, J6.GND6, JP13.1, JP14.1, JP15.1, JP16.1, Q8.2, R85.1, R99.1, R103.1, U13.4, U14.3, U14.9, U14.14, U14.16, U14.19, U14.29, U14.48, U15.2, U16.3
GND4: C105.2, C106.2, C107.2, C108.2, C109.2, C110.2, C111.2, C112.2, C113.2, C114.2, C115.2, C116.2, C117.2, C118.2, C119.2, C120.2, C121.2, C122.2, C125.2, C126.2, C127.-, C128.2, C129.2, C130.2, D17.C, D19.C, J8.1, J8.33, J8.39, J8.45, J8.75, J8.GND1, J8.GND2, J8.GND3, J8.GND4, J8.GND5, J8.GND6, JP17.1, JP18.1, JP19.1, JP20.1, Q10.2, R111.1, R125.1, R129.1, U17.4, U18.3, U18.9, U18.14, U18.16, U18.19, U18.29, U18.48, U19.2, U20.3
GND5: C131.2, C132.2, C133.2, C134.2, C135.2, C136.2, C137.2, C138.2, C139.2, C140.2, C141.2, C142.2, C143.2, C144.2, C145.2, C146.2, C147.2, C148.2, C151.2, C152.2, C153.-, C154.2, C155.2, C156.2, D21.C, D23.C, J10.1, J10.33, J10.39, J10.45, J10.75, J10.GND1, J10.GND2, J10.GND3, J10.GND4, J10.GND5, J10.GND6, JP21.1, JP22.1, JP23.1, JP24.1, Q12.2, R137.1, R151.1, R155.1, U21.4, U22.3, U22.9, U22.14, U22.16, U22.19, U22.29, U22.48, U23.2, U24.3
GND-ISO: C19.1, D7.2, J1.7, J1.8, J1.S1, J1.S2
GND-ISO1: C43.1, D8.2, J3.7, J3.8, J3.S1, J3.S2
GND-ISO2: C69.1, D12.2, J5.7, J5.8, J5.S1, J5.S2
GND-ISO3: C95.1, D16.2, J7.7, J7.8, J7.S1, J7.S2
GND-ISO4: C121.1, D20.2, J9.7, J9.8, J9.S1, J9.S2
GND-ISO5: C147.1, D24.2, J12.7, J12.8, J12.S1, J12.S2
I2C_SCL: J11.21, U1.6
I2C_SCL1: J2.21, U2.6
I2C_SCL2: J4.21, U9.6
I2C_SCL3: J6.21, U13.6
I2C_SCL4: J8.21, U17.6
I2C_SCL5: J10.21, U21.6
I2C_SDA: J11.19, U1.5
I2C_SDA1: J2.19, U2.5
I2C_SDA2: J4.19, U9.5
I2C_SDA3: J6.19, U13.5
I2C_SDA4: J8.19, U17.5
I2C_SDA5: J10.19, U21.5
LINK_LED: LED1.2, U3.25
LINK_LED1: LED3.2, U6.25
LINK_LED2: LED5.2, U10.25
LINK_LED3: LED7.2, U14.25
LINK_LED4: LED9.2, U18.25
LINK_LED5: LED11.2, U22.25
unnamed: C5.1, R1.1, U3.31, Y1.1
unnamed: C6.1, R1.2, U3.30, Y1.3
unnamed: J1.14, LED2.1
unnamed: J1.12, LED1.1
unnamed: D5.A, R11.1
unnamed: POE_LED.1, R11.2
unnamed: D1.C, POE.1
unnamed: J1.13, R5.1
unnamed: LOAD.1, R2.2
unnamed: J1.11, R3.1
unnamed: Q1.3, Q5.1, R7.1
unnamed: POE_LED1.1, R26.2
unnamed: R8.2, U3.10
unnamed: D3.A, R26.1
unnamed: C17.1, U3.22
unnamed: C18.1, U3.20
unnamed: R30.2, U3.23
unnamed: Q2.1, Q3.3, R28.1
unnamed: PWR_LED.1, R25.2
unnamed: D2.A, R25.1
unnamed: C31.1, R29.1, U6.31, Y2.1
unnamed: C32.1, R29.2, U6.30, Y2.3
unnamed: J3.13, R32.1
unnamed: J3.11, R31.1
unnamed: R33.2, U6.10
unnamed: C41.1, U6.22
unnamed: C42.1, U6.20
unnamed: D4.C, POE1.1
unnamed: LOAD1.1, R47.2
unnamed: J3.12, LED3.1
unnamed: J3.14, LED4.1
unnamed: R51.2, U6.23
unnamed: PWR_LED1.1, R52.2
unnamed: D6.A, R52.1
unnamed: POE_LED2.1, R53.2
unnamed: D9.A, R53.1
unnamed: Q4.1, Q6.3, R55.1
unnamed: C57.1, R56.1, U10.31, Y3.1
unnamed: C58.1, R56.2, U10.30, Y3.3
unnamed: J5.13, R58.1
unnamed: J5.11, R57.1
unnamed: R59.2, U10.10
unnamed: C67.1, U10.22
unnamed: C68.1, U10.20
unnamed: D10.C, POE2.1
unnamed: LOAD2.1, R73.2
unnamed: J5.12, LED5.1
unnamed: J5.14, LED6.1
unnamed: R77.2, U10.23
unnamed: PWR_LED2.1, R78.2
unnamed: D11.A, R78.1
unnamed: POE_LED3.1, R79.2
unnamed: D13.A, R79.1
unnamed: Q7.1, Q8.3, R81.1
unnamed: C83.1, R82.1, U14.31, Y4.1
unnamed: C84.1, R82.2, U14.30, Y4.3
unnamed: J7.13, R84.1
unnamed: J7.11, R83.1
unnamed: R85.2, U14.10
unnamed: C93.1, U14.22
unnamed: C94.1, U14.20
unnamed: D14.C, POE3.1
unnamed: LOAD3.1, R99.2
unnamed: J7.12, LED7.1
unnamed: J7.14, LED8.1
unnamed: R103.2, U14.23
unnamed: PWR_LED3.1, R104.2
unnamed: D15.A, R104.1
unnamed: POE_LED4.1, R105.2
unnamed: D17.A, R105.1
unnamed: Q9.1, Q10.3, R107.1
unnamed: C109.1, R108.1, U18.31, Y5.1
unnamed: C110.1, R108.2, U18.30, Y5.3
unnamed: J9.13, R110.1
unnamed: J9.11, R109.1
unnamed: R111.2, U18.10
unnamed: C119.1, U18.22
unnamed: C120.1, U18.20
unnamed: D18.C, POE4.1
unnamed: LOAD4.1, R125.2
unnamed: J9.12, LED9.1
unnamed: J9.14, LED10.1
unnamed: R129.2, U18.23
unnamed: PWR_LED4.1, R130.2
unnamed: D19.A, R130.1
unnamed: POE_LED5.1, R131.2
unnamed: D21.A, R131.1
unnamed: Q11.1, Q12.3, R133.1
unnamed: C135.1, R134.1, U22.31, Y6.1
unnamed: C136.1, R134.2, U22.30, Y6.3
unnamed: J12.13, R136.1
unnamed: J12.11, R135.1
unnamed: R137.2, U22.10
unnamed: C145.1, U22.22
unnamed: C146.1, U22.20
unnamed: D22.C, POE5.1
unnamed: LOAD5.1, R151.2
unnamed: J12.12, LED11.1
unnamed: J12.14, LED12.1
unnamed: R155.2, U22.23
unnamed: PWR_LED5.1, R156.2
unnamed: D23.A, R156.1
PMODE0: JP1.2, R9.1, U3.45
PMODE1: JP2.2, R10.1, U3.44
PMODE2: JP3.2, R12.1, U3.43
PMODE3: JP4.2, R34.1, U6.45
PMODE4: JP6.2, R35.1, U6.44
PMODE5: JP7.2, R36.1, U6.43
PMODE6: JP9.2, R60.1, U10.45
PMODE7: JP10.2, R61.1, U10.44
PMODE8: JP11.2, R62.1, U10.43
PMODE9: JP13.2, R86.1, U14.45
PMODE10: JP14.2, R87.1, U14.44
PMODE11: JP15.2, R88.1, U14.43
PMODE12: JP17.2, R112.1, U18.45
PMODE13: JP18.2, R113.1, U18.44
PMODE14: JP19.2, R114.1, U18.43
PMODE15: JP21.2, R138.1, U22.45
PMODE16: JP22.2, R139.1, U22.44
PMODE17: JP23.2, R140.1, U22.43
PW1+: ISO1.2, ISO1.4, U5.5, U5.6
PW1+1: ISO3.2, ISO3.4, U8.5, U8.6
PW1+2: ISO5.2, ISO5.4, U12.5, U12.6
PW1+3: ISO7.2, ISO7.4, U16.5, U16.6
PW1+4: ISO9.2, ISO9.4, U20.5, U20.6
PW1+5: ISO11.2, ISO11.4, U24.5, U24.6
PW1-: ISO2.2, ISO2.4, U5.7, U5.8
PW1-1: ISO4.2, ISO4.4, U8.7, U8.8
PW1-2: ISO6.2, ISO6.4, U12.7, U12.8
PW1-3: ISO8.2, ISO8.4, U16.7, U16.8
PW1-4: ISO10.2, ISO10.4, U20.7, U20.8
PW1-5: ISO12.2, ISO12.4, U24.7, U24.8
PW+: ISO1.1, ISO1.3, J1.9
PW+1: ISO3.1, ISO3.3, J3.9
PW+2: ISO5.1, ISO5.3, J5.9
PW+3: ISO7.1, ISO7.3, J7.9
PW+4: ISO9.1, ISO9.3, J9.9
PW+5: ISO11.1, ISO11.3, J12.9
PW-: ISO2.1, ISO2.3, J1.10
PW-1: ISO4.1, ISO4.3, J3.10
PW-2: ISO6.1, ISO6.3, J5.10
PW-3: ISO8.1, ISO8.3, J7.10
PW-4: ISO10.1, ISO10.3, J9.10
PW-5: ISO12.1, ISO12.3, J12.10
PWR_EN: J11.71, Q1.1, R6.2, U4.3
PWR_EN1: J2.71, Q3.1, R27.2, U7.3
PWR_EN2: J4.71, Q6.1, R54.2, U11.3
PWR_EN3: J6.71, Q8.1, R80.2, U15.3
PWR_EN4: J8.71, Q10.1, R106.2, U19.3
PWR_EN5: J10.71, Q12.1, R132.2, U23.3
RCT: C20.1, J1.5, R13.1, R18.1
RCT1: C44.1, J3.5, R37.1, R42.1
RCT2: C70.1, J5.5, R63.1, R68.1
RCT3: C96.1, J7.5, R89.1, R94.1
RCT4: C122.1, J9.5, R115.1, R120.1
RCT5: C148.1, J12.5, R141.1, R146.1
RD+: C22.2, D7.3, J1.3
RD+1: C46.2, D8.3, J3.3
RD+2: C72.2, D12.3, J5.3
RD+3: C98.2, D16.3, J7.3
RD+4: C124.2, D20.3, J9.3
RD+5: C150.2, D24.3, J12.3
RD-: C21.2, D7.4, J1.6
RD-1: C45.2, D8.4, J3.6
RD-2: C71.2, D12.4, J5.6
RD-3: C97.2, D16.4, J7.6
RD-4: C123.2, D20.4, J9.6
RD-5: C149.2, D24.4, J12.6
RXN: R17.1, U3.5
RXN1: C21.1, R17.2, R18.2
RXN2: R41.1, U6.5
RXN3: C45.1, R41.2, R42.2
RXN4: R67.1, U10.5
RXN5: C71.1, R67.2, R68.2
RXN6: R93.1, U14.5
RXN7: C97.1, R93.2, R94.2
RXN8: R119.1, U18.5
RXN9: C123.1, R119.2, R120.2
RXN10: R145.1, U22.5
RXN11: C149.1, R145.2, R146.2
RXP: R16.1, U3.6
RXP1: C22.1, R13.2, R16.2
RXP2: R40.1, U6.6
RXP3: C46.1, R37.2, R40.2
RXP4: R66.1, U10.6
RXP5: C72.1, R63.2, R66.2
RXP6: R92.1, U14.6
RXP7: C98.1, R89.2, R92.2
RXP8: R118.1, U18.6
RXP9: C124.1, R115.2, R118.2
RXP10: R144.1, U22.6
RXP11: C150.1, R141.2, R144.2
SPI_CIPO: J11.7, U3.34
SPI_CIPO1: J2.7, U6.34
SPI_CIPO2: J4.7, U10.34
SPI_CIPO3: J6.7, U14.34
SPI_CIPO4: J8.7, U18.34
SPI_CIPO5: J10.7, U22.34
SPI_COPI: J11.5, U3.35
SPI_COPI1: J2.5, U6.35
SPI_COPI2: J4.5, U10.35
SPI_COPI3: J6.5, U14.35
SPI_COPI4: J8.5, U18.35
SPI_COPI5: J10.5, U22.35
SPI_SCK: J11.3, U3.33
SPI_SCK1: J2.3, U6.33
SPI_SCK2: J4.3, U10.33
SPI_SCK3: J6.3, U14.33
SPI_SCK4: J8.3, U18.33
SPI_SCK5: J10.3, U22.33
TCT: C23.1, J1.4, R21.1
TCT1: C47.1, J3.4, R45.1
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

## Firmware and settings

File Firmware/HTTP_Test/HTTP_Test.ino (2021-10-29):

/*
  Web client

 This sketch connects to a website (http://www.google.com)
 using an Arduino Wiznet Ethernet shield.

 Circuit:
 * Ethernet shield attached to pins 10, 11, 12, 13

 created 18 Dec 2009
 by David A. Mellis
 modified 9 Apr 2012
 by Tom Igoe, based on work by Adrian McEwen

 */

#include <SPI.h>
#include <Ethernet.h>
//#include "src/Ethernet/Ethernet.h"

// Enter a MAC address for your controller below.
// Newer Ethernet shields have a MAC address printed on a sticker on the shield
byte mac[] = { 0xDE, 0xAD, 0xBE, 0xEF, 0xFE, 0xED };

// if you don't want to use DNS (and reduce your sketch size)
// use the numeric IP instead of the name for the server:
//IPAddress server(74,125,232,128);  // numeric IP for Google (no DNS)
char server[] = "www.google.com";    // name address for Google (using DNS)

// Set the static IP address to use if the DHCP fails to assign
IPAddress ip(192, 168, 0, 177);
IPAddress myDns(192, 168, 0, 1);

// Initialize the Ethernet client library
// with the IP address and port of the server
// that you want to connect to (port 80 is default for HTTP):
EthernetClient client;

// Variables to measure the speed
unsigned long beginMicros, endMicros;
unsigned long byteCount = 0;
bool printWebData = false;  // set to false for better speed measurement

void setup() {
  //Ethernet.init(CS); //SAMD51 248kb/s
  //Ethernet.init(10); //Teensy 228kb/s
  //Ethernet.init(5); //ESP32 192kb/s
  //Ethernet.init(5); //nRF fails
  //Ethernet.init(5); //Artemis fails
  Ethernet.init(A4); //STM32

  Serial.begin(115200);

  delay(4000);

  // start the Ethernet connection:
  Serial.println("Initialize Ethernet with DHCP:");
  if (Ethernet.begin(mac) == 0) {
    Serial.println("Failed to configure Ethernet using DHCP");
    // Check for Ethernet hardware present
    if (Ethernet.hardwareStatus() == EthernetNoHardware) {
      Serial.println("Ethernet shield was not found.  Sorry, can't run without hardware. :(");
      while (true) {
        delay(1000);
        Serial.println("Not detected");
        delay(1); // do nothing, no point running without Ethernet hardware
      }
    }
    if (Ethernet.linkStatus() == LinkOFF) {
      Serial.println("Ethernet cable is not connected.");
    }
    // try to congifure using IP address instead of DHCP:
    Ethernet.begin(mac, ip, myDns);
  } else {
    Serial.print("  DHCP assigned IP ");
    Serial.println(Ethernet.localIP());
  }
  // give the Ethernet shield a second to initialize:
  delay(1000);
  Serial.print("connecting to ");
  Serial.print(server);
  Serial.println("...");

  // if you get a connection, report back via serial:
  if (client.connect(server, 80)) {
    Serial.print("connected to ");
    Serial.println(client.remoteIP());
    // Make a HTTP request:
    client.println("GET /search?q=arduino HTTP/1.1");
    client.println("Host: www.google.com");
    client.println("Connection: close");
    client.println();
  } else {
    // if you didn't get a connection to the server:
    Serial.println("connection failed");
  }
  beginMicros = micros();
}

void loop() {
  // if there are incoming bytes available
  // from the server, read them and print them:
  int len = client.available();
  if (len > 0) {
//    byte buffer[80];
    byte buffer[512 * 4];
    if (len > sizeof(buffer)) len = sizeof(buffer);
    client.read(buffer, len);
    if (printWebData) {
      Serial.write(buffer, len); // show in the serial monitor (slows some boards)
    }
    byteCount = byteCount + len;
  }

  // if the server's disconnected, stop the client:
  if (!client.connected()) {
    endMicros = micros();
    Serial.println();
    Serial.println("disconnecting.");
    client.stop();
    Serial.print("Received ");
    Serial.print(byteCount);
    Serial.print(" bytes in ");
    float seconds = (float)(endMicros - beginMicros) / 1000000.0;
    Serial.print(seconds, 4);
    float rate = (float)byteCount / seconds / 1000.0;
    Serial.print(", rate = ");
    Serial.print(rate);
    Serial.print(" kbytes/second");
    Serial.println();

    // do nothing forevermore:
    while (true) {
      delay(1);
    }
  }
}

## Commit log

2021-09-14 Update PoE module to DP990X.
    [MicroMod-Ethernet-Function-Board.brd, MicroMod-Ethernet-Function-Board.sch]
2021-09-20 Add x01 panel files
    [MicroMod-Ethernet-Function-Board-Panel.GBL, MicroMod-Ethernet-Function-Board-Panel.GBO, MicroMod-Ethernet-Function-Board-Panel.GBP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]
2021-09-21 Update PROD_IDs
    [MicroMod-Ethernet-Function-Board.brd, MicroMod-Ethernet-Function-Board.sch]
2021-09-21 Remove old files
    [MicroMod-LoRa-1W-Function-Board-Panel.GBL, MicroMod-LoRa-1W-Function-Board-Panel.GBO, MicroMod-LoRa-1W-Function-Board-Panel.GBP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]
2021-09-21 Change load resistor to 1206.
    [MicroMod-Ethernet-Function-Board.brd, MicroMod-Ethernet-Function-Board.sch]
2021-10-27 Connect PWR LED to 3.3V rail. Add POE LED. Add pin 1 indicator to PoE module. Add hot caution.
    [MicroMod-Ethernet-Function-Board.brd, MicroMod-Ethernet-Function-Board.sch]
2021-11-05 Add ESD to TX/RX, landmarks to PoE module, additional GND thermals.
    [MicroMod-Ethernet-Function-Board-Panel.GBL, MicroMod-Ethernet-Function-Board-Panel.GBO, MicroMod-Ethernet-Function-Board-Panel.GBS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]
2021-11-08 Add dimensions
    [MicroMod-Ethernet-Function-Board.brd]
2022-03-02 Add -W5500 to file names
    [MicroMod-Ethernet-Function-Board-Panel-W5500.brd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]
2022-03-02 Mark ESD IC as DNP
    [MicroMod-Ethernet-Function-Board-W5500.sch]

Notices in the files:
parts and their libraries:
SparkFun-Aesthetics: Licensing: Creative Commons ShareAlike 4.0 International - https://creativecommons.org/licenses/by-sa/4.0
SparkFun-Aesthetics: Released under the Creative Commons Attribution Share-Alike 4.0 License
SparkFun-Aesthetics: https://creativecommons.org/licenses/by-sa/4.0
